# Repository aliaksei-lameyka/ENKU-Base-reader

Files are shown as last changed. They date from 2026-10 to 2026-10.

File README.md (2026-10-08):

# ENKU Base Reader

ENKU Base Reader is an independently developed, compact **3.97-inch e-paper reader** built around a custom ESP32-S3 mainboard. The goal is an inspectable, repairable, local-first reading device with physical controls, removable storage, and no required cloud account or subscription for reading locally stored books.

> **Status: Base R0.1 — engineering / first-spin development.** The board has **not** passed its fabrication release gate. Files in this repository are not a PCBWay-ready production package.

## Base R0.1 at a glance

| Area | Current engineering baseline |
| --- | --- |
| Display | 3.97-inch, 800 × 480 e-paper panel interface; 24-pin FPC |
| MCU | ESP32-S3-WROOM-1-N16R8 |
| PCB | 4 layers; 54 × 94 mm current outline; portrait-first |
| Storage and connectivity | microSD, USB-C |
| Navigation | Four side-edge buttons, two per side, for configurable left/right-handed controls |
| Motion sensing | BMI270 IMU |
| Power | Li-ion charging, USB/dock power-path handling, 3.3 V regulation, hard power switch |
| Dock | Rear dock connection and detection interface |

A Hall sensor is **still present in the current R0.1 design**, but its necessity is under review: Base is not being designed around a magnetic cover. Its presence in the design files should not be interpreted as a committed product feature.

**Outside the Base R0.1 scope:** frontlight and wireless charging. A separate, more fully featured variant may address these later; no Pro hardware is released here.

## Current work and limitations

The KiCad schematics, PCB, project-local libraries, and structural validation scripts are available. Routing closure, display-flex geometry, component orientation, mechanical interfaces, and manufacturing-file review are still release blockers.

The engineering goals are low-power operation, repairability, and reproducibility; they are **design goals, not yet verified production specifications**. Firmware and enclosure sources are not yet published in this repository.

## Repository guide

- [KiCad source and validation scripts](hardware/mainboard/kicad/) — editable mainboard design and engineering checks
- [Mainboard notes](hardware/mainboard/README.md) — current hardware release scope
- [Hardware overview](docs/hardware.md) — interfaces, controls, and mechanical envelope
- [Validation and fabrication gate](docs/validation.md) — checks required before ordering boards
- [Manufacturing notes](docs/manufacturing.md) — release package expectations
- [CI workflows](.github/workflows/) — structural and native KiCad checks

Manufacturing outputs (Gerber, drill, BOM, CPL, and assembly notes) will be published under `hardware/mainboard/production/<revision>/` **only after** a revision is approved for fabrication.

## Running the lightweight checks

From the repository root, with Python 3:

```sh
python3 hardware/mainboard/kicad/check_schematics.py
python3 hardware/mainboard/kicad/check_pcb_placement.py
python3 hardware/mainboard/kicad/check_footprint_consistency.py
python3 hardware/mainboard/kicad/check_pcb_population.py
```

These scripts catch structural and placement regressions. **They are not substitutes for native KiCad ERC/DRC** or an electrical/mechanical review. The repository includes a native KiCad workflow for pull requests and manual execution; a passing workflow alone does not authorize fabrication. See the [release checklist](docs/validation.md).

## Revisions

| Revision | Purpose | Status |
| --- | --- | --- |
| Base R0.1 | First engineering board / EVT | In development |
| Base R0.2 | Bring-up and first-spin corrections | Planned |
| Base R1.0 | Production candidate | Planned |

## Licensing

ENKU Base Reader uses **different licenses for different types of work**:

- **Original hardware design** — [CERN-OHL-W-2.0](LICENSE), including the KiCad PCB/schematic design and ENKU-authored hardware files.
- **Software and automation scripts** — [MIT](LICENSES/MIT.txt), including the Python validation tools and any future firmware expressly released in this repository.
- **Original project documentation** — [CC BY 4.0](LICENSES/CC-BY-4.0.txt), including README files and `docs/`.

Read the [license scope and third-party exceptions](LICENSE.md) before redistributing files or manufacturing modified boards. Third-party materials keep their own terms. The ENKU name and logos are not granted as trademarks by these licenses.

## Related project

[ENKU Originals](https://github.com/aliaksei-lameyka/ENKU-Originals) is a separate, early-stage experiment in AI-assisted, human-edited short fiction and reader-first EPUB delivery. It is currently private. **Its stories and editorial content are not licensed by this repository.**

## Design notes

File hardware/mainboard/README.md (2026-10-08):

# ENKU Base mainboard

Editable **Base R0.1** schematic, PCB and local KiCad libraries are stored in [`kicad/`](kicad/).

This is an **engineering first-spin**, not a fabrication-ready or production release. Before any manufacturing order, complete the [fabrication release checklist](../../docs/validation.md), including native KiCad ERC/DRC, connector orientation, component selections, display FPC fit and manufacturing-output review.

The Base does **not** include frontlight or wireless-charging circuitry. Those are outside this board's scope.

The original ENKU hardware design is licensed under **CERN-OHL-W-2.0**; see the repository [licensing guide](../../LICENSE.md). Automation scripts in `kicad/` are under MIT.

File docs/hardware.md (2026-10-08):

# Hardware overview

## Base R0.1

Base R0.1 is a four-layer mainboard for the compact ENKU reader.

### Compute and storage

- ESP32-S3-WROOM-1-N16R8
- microSD
- USB-C USB 2.0 connection

### Display

The board carries a dedicated 24-pin e-paper interface and local high-voltage generation for the 3.97-inch panel class used by the first reader prototype. The display FPC orientation and bend path still require mechanical verification.

### Power

The power architecture includes USB/dock source handling, Li-ion charging, a hard power control path and a 3.3 V system rail.

### Input and sensing

- Two reading buttons on each side edge
- BMI270 IMU
- Hall sensor **present in the current design, under review for Base**
- Service/debug interface
- Dock detect

The four reading buttons are intentionally symmetric so firmware can support left-handed and right-handed layouts. A magnetic-cover feature is **not** in the Base product scope; the Hall sensor's inclusion is therefore not yet a final feature decision.

### Base scope

Frontlight and wireless charging are not part of Base R0.1. Keeping those features out of the first-spin board reduces routing and validation complexity and lets the Base hardware reach bring-up sooner.

## Mechanical envelope

The current PCB outline is 54 × 94 mm in portrait orientation.

Mechanical release still requires final validation of the display flex path, USB-C opening, microSD insertion envelope, battery lead exit, dock contact face, hard-power actuator and side-button actuators against the enclosure master.

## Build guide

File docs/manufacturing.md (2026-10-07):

# Manufacturing notes

Base R0.1 is an engineering first-spin board. Manufacturing outputs are not considered authoritative until the fabrication release gate is closed.

## Board

- 4 layers
- 54 × 94 mm outline
- portrait primary orientation

The KiCad source under `hardware/mainboard/kicad/` is the editable source of truth.

## Assembly package

A release package will contain:

- Gerber files
- NC drill files
- BOM
- pick-and-place / CPL
- assembly notes
- board preview
- revision identifier

Generated outputs belong under `hardware/mainboard/production/<revision>/` and should not be edited by hand.

## First-spin priorities

For the first fabrication run, debug access and repairability take priority over cosmetic density. Important power rails and e-paper high-voltage rails retain measurement access where practical.

Component reference markings and polarity/orientation cues should remain readable after assembly wherever board space allows.

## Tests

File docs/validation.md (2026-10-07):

# Validation

The repository uses two levels of checks.

## Lightweight checks

Structural checks run on hardware changes and catch issues that do not require KiCad itself:

- schematic hierarchy integrity
- required Base references and nets
- PCB population parity
- project-local footprint consistency
- placement and orientation invariants
- selected routing regression checks

These checks are intentionally fast.

## Native KiCad checks

Native KiCad ERC and DRC are the authority for electrical and PCB-rule validation.

They are used at meaningful engineering gates rather than as an interactive router. A passing structural check does not replace native ERC/DRC.

## Fabrication release gate

Before Base R0.1 can be released for fabrication, the board must have:

1. final Base routing closed;
2. no unexplained ERC errors;
3. no fabrication-blocking DRC violations;
4. final battery connector selected and polarity verified;
5. final hard-power switch selected and actuator geometry verified;
6. final side-button switch selected and enclosure interaction verified;
7. e-paper FPC pin 1, contact side and bend path verified against the selected panel;
8. USB-C and microSD mechanical access checked against enclosure geometry;
9. dock pogo face and pin order checked;
10. Gerber, drill, BOM and pick-and-place outputs visually reviewed.

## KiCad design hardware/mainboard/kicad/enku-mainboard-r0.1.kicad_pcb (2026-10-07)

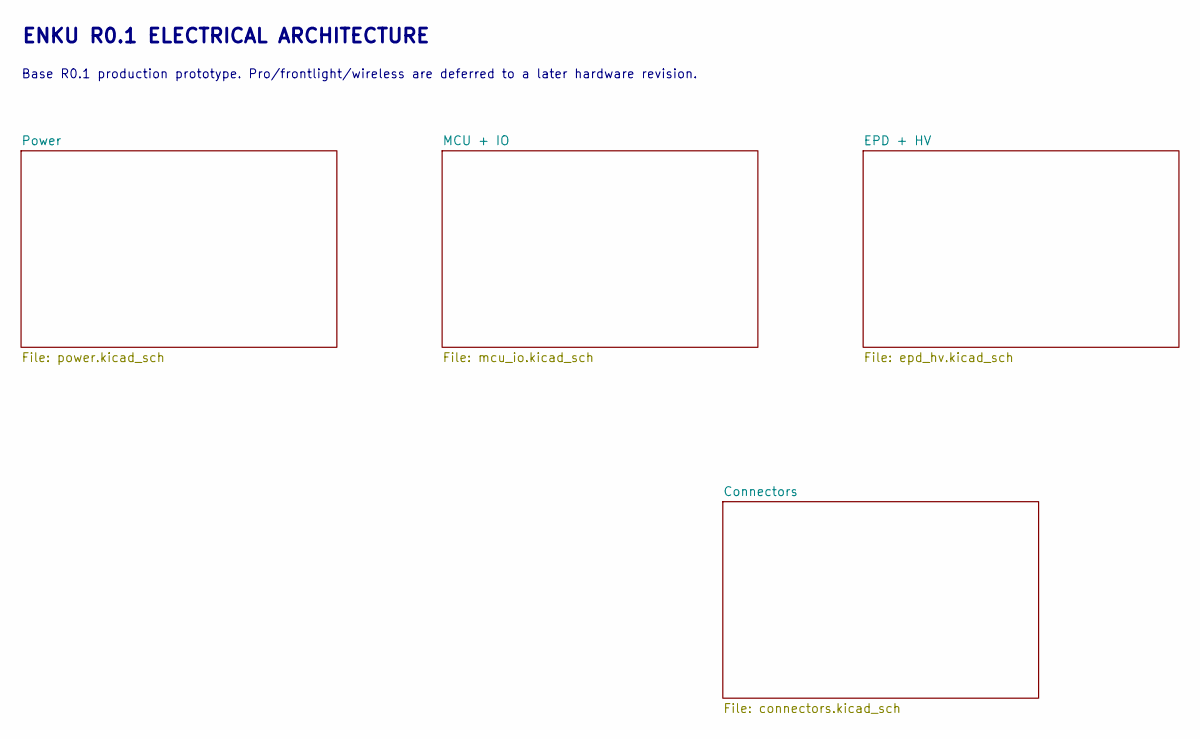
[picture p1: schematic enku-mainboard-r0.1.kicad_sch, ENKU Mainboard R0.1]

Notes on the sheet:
ENKU R0.1 ELECTRICAL ARCHITECTURE
Base R0.1 production prototype. Pro/frontlight/wireless are deferred to a later hardware revision.

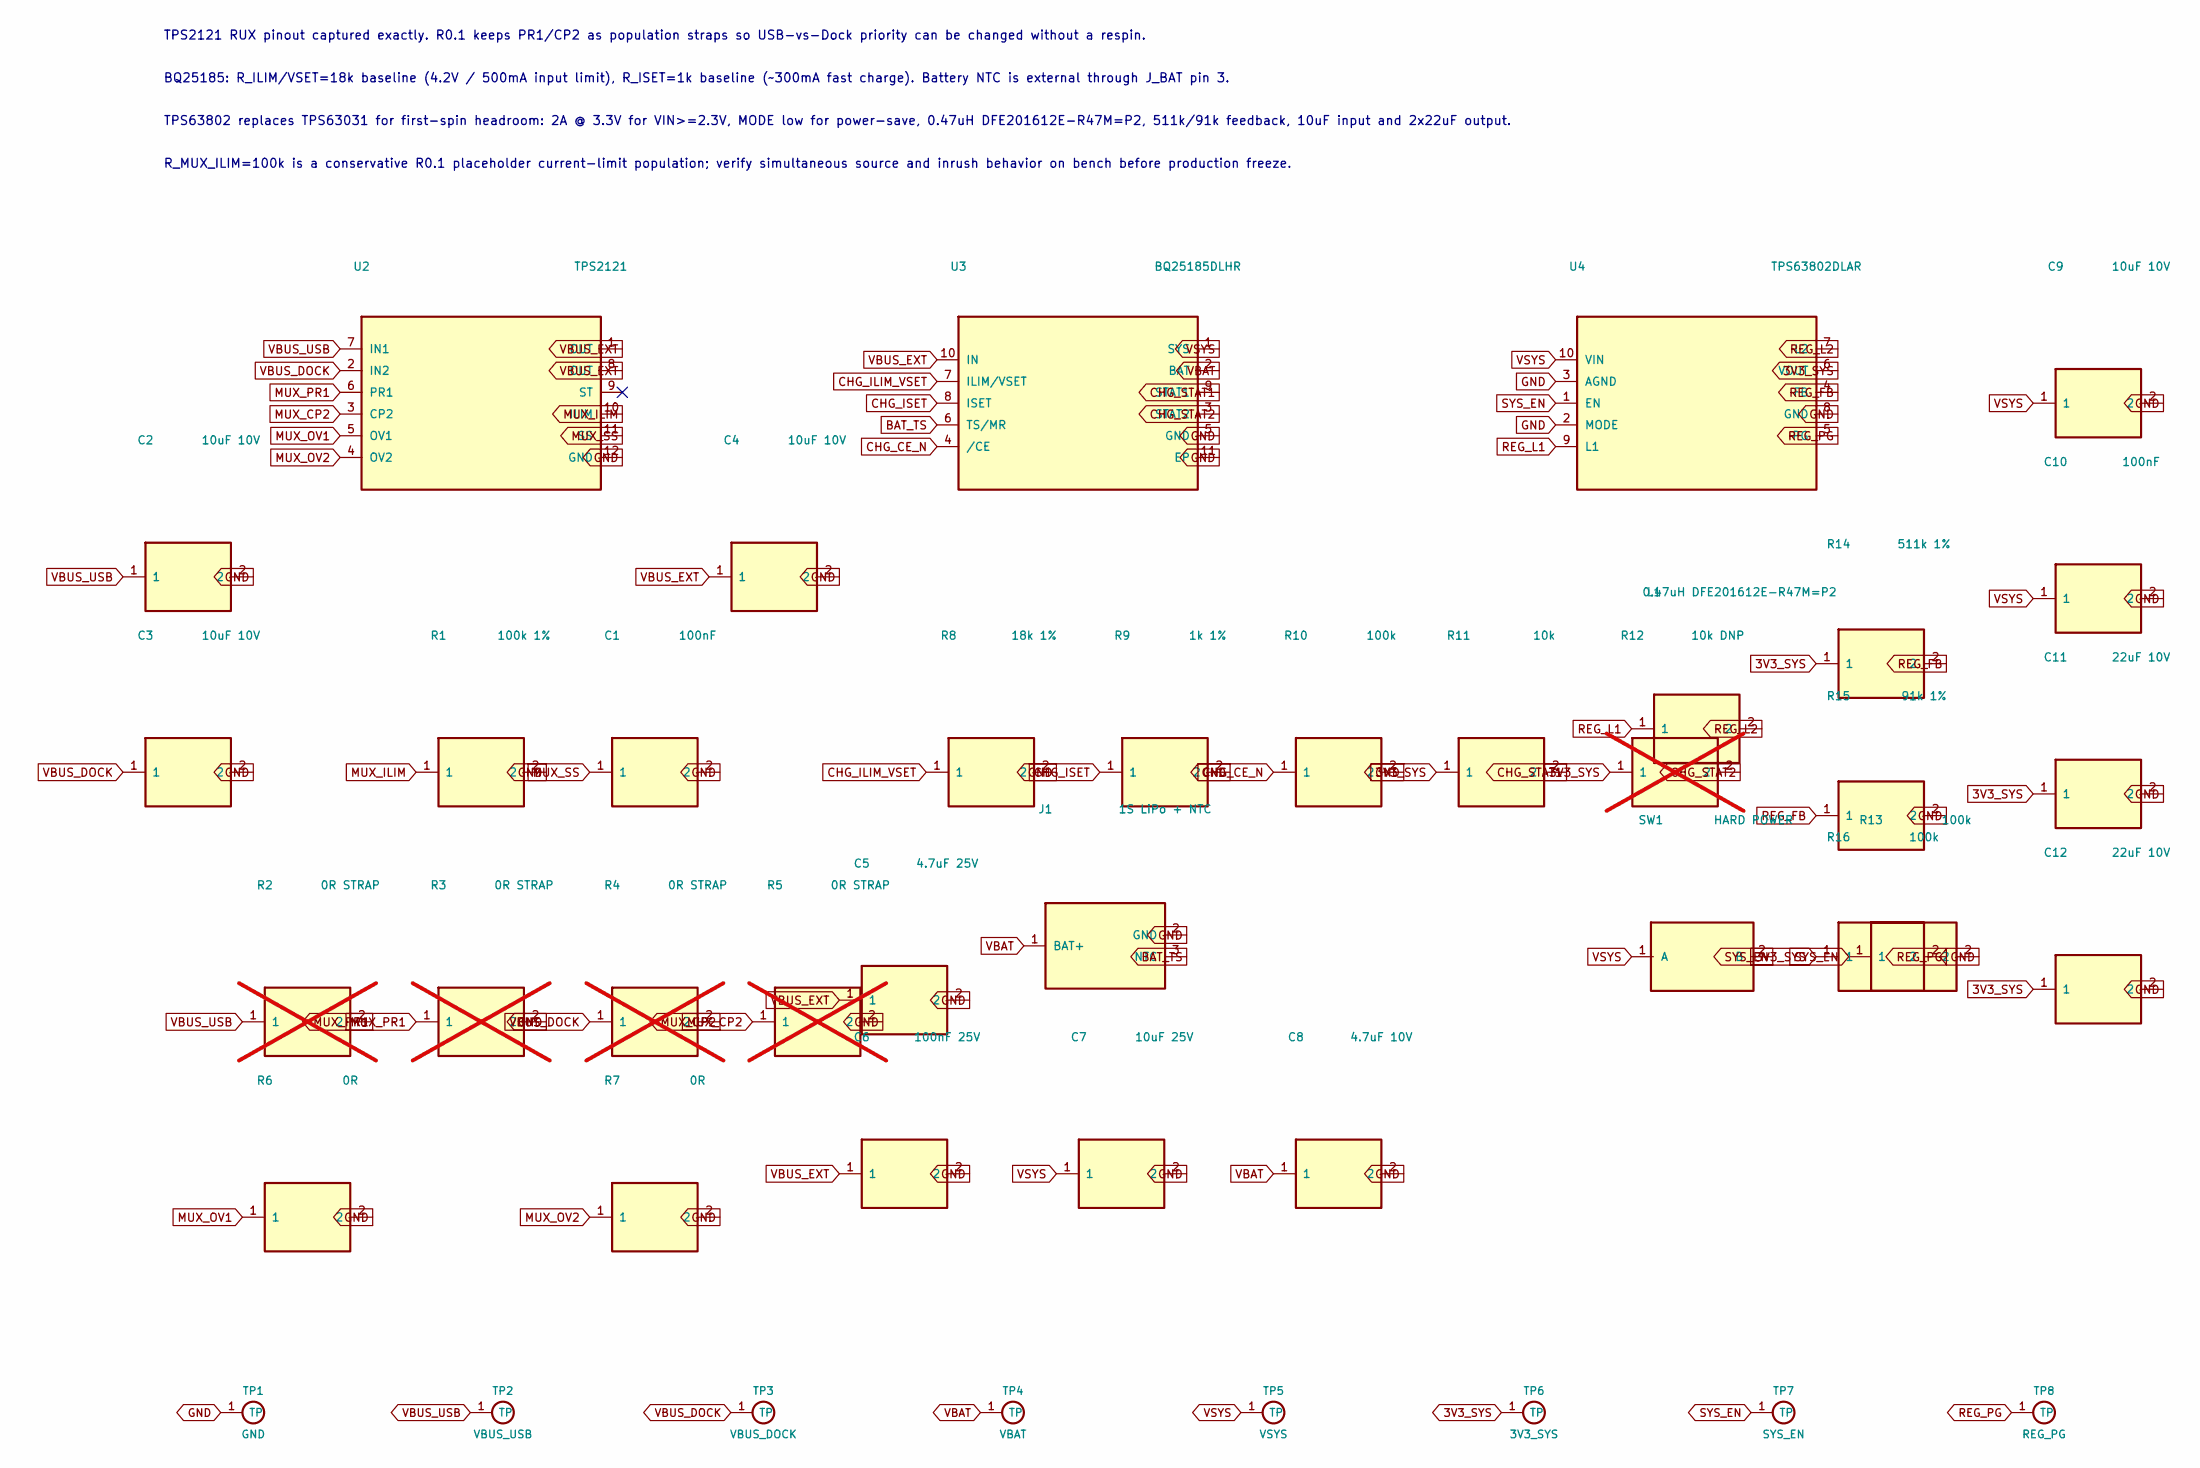
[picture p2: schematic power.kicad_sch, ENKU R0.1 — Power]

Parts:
C1, C10: 100nF; C_0603_1608Metric
C2, C3, C4, C9: 10uF 10V; C_0805_2012Metric
C5: 4.7uF 25V; C_0805_2012Metric
C6: 100nF 25V; C_0603_1608Metric
C7: 10uF 25V; C_0805_2012Metric
C8: 4.7uF 10V; C_0805_2012Metric
C11, C12: 22uF 10V; C_0805_2012Metric
J1: 1S LiPo + NTC; JST_PH_3_PLACEMENT
L1: 0.47uH DFE201612E-R47M=P2; Murata_DFE201612E
R1: 100k 1%; R_0603_1608Metric
R2, R3, R4, R5: 0R STRAP; R_0603_1608Metric; not fitted
R6, R7: 0R; R_0603_1608Metric
R8: 18k 1%; R_0603_1608Metric
R9: 1k 1%; R_0603_1608Metric
R10, R13, R16: 100k; R_0603_1608Metric
R11: 10k; R_0603_1608Metric
R12: 10k DNP; R_0603_1608Metric; not fitted
R14: 511k 1%; R_0603_1608Metric
R15: 91k 1%; R_0603_1608Metric
SW1: HARD POWER; HARD_POWER_SWITCH_PLACEMENT
TP1: GND; TestPoint_Pad_D1.5mm
TP2: VBUS_USB; TestPoint_Pad_D1.5mm
TP3: VBUS_DOCK; TestPoint_Pad_D1.5mm
TP4: VBAT; TestPoint_Pad_D1.5mm
TP5: VSYS; TestPoint_Pad_D1.5mm
TP6: 3V3_SYS; TestPoint_Pad_D1.5mm
TP7: SYS_EN; TestPoint_Pad_D1.5mm
TP8: REG_PG; TestPoint_Pad_D1.5mm
U2: TPS2121; TPS2121_RUX0012A
U3: BQ25185DLHR; BQ25185_DLH0010A
U4: TPS63802DLAR; TPS63802_DLA0010A

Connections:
3V3_SYS: C11.1, C12.1, R11.1, R12.1, R14.1, R16.1, TP6.1, U4.6 (VOUT); also elsewhere on the board
BAT_TS: J1.3 (NTC), U3.6 (TS/MR)
CHG_CE_N: R10.1, U3.4 (/CE)
CHG_ILIM_VSET: R8.1, U3.7 (ILIM/VSET)
CHG_ISET: R9.1, U3.8 (ISET)
CHG_STAT1: R11.2, U3.9 (STAT1); also elsewhere on the board
CHG_STAT2: R12.2, U3.3 (STAT2)
GND: C1.2, C2.2, C3.2, C4.2, C5.2, C6.2, C7.2, C8.2, C9.2, C10.2, C11.2, C12.2, J1.2 (GND), R1.2, R3.2, R5.2, R6.2, R7.2, R8.2, R9.2, R10.2, R13.2, R15.2, TP1.1, U2.12 (GND), U3.5 (GND), U3.11 (EP), U4.2 (MODE), U4.3 (AGND), U4.8 (GND); also elsewhere on the board
MUX_CP2: R4.2, R5.1, U2.3 (CP2)
MUX_ILIM: R1.1, U2.10 (ILIM)
MUX_OV1: R6.1, U2.5 (OV1)
MUX_OV2: R7.1, U2.4 (OV2)
MUX_PR1: R2.2, R3.1, U2.6 (PR1)
MUX_SS: C1.1, U2.11 (SS)
REG_FB: R14.2, R15.1, U4.4 (FB)
REG_L1: L1.1, U4.9 (L1)
REG_L2: L1.2, U4.7 (L2)
REG_PG: R16.2, TP8.1, U4.5 (PG)
SYS_EN: R13.1, SW1.2 (B), TP7.1, U4.1 (EN)
VBAT: C8.1, J1.1 (BAT+), TP4.1, U3.2 (BAT); also elsewhere on the board
VBUS_DOCK: C3.1, R4.1, TP3.1, U2.2 (IN2); also elsewhere on the board
VBUS_EXT: C4.1, C5.1, C6.1, U2.1 (OUT), U2.8 (OUT), U3.10 (IN)
VBUS_USB: C2.1, R2.1, TP2.1, U2.7 (IN1); also elsewhere on the board
VSYS: C7.1, C9.1, C10.1, SW1.1 (A), TP5.1, U3.1 (SYS), U4.10 (VIN)

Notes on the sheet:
TPS2121 RUX pinout captured exactly. R0.1 keeps PR1/CP2 as population straps so USB-vs-Dock priority can be changed without a respin.
BQ25185: R_ILIM/VSET=18k baseline (4.2V / 500mA input limit), R_ISET=1k baseline (~300mA fast charge). Battery NTC is external through J_BAT pin 3.
TPS63802 replaces TPS63031 for first-spin headroom: 2A @ 3.3V for VIN>=2.3V, MODE low for power-save, 0.47uH DFE201612E-R47M=P2, 511k/91k feedback, 10uF input and 2x22uF output.
R_MUX_ILIM=100k is a conservative R0.1 placeholder current-limit population; verify simultaneous source and inrush behavior on bench before production freeze.

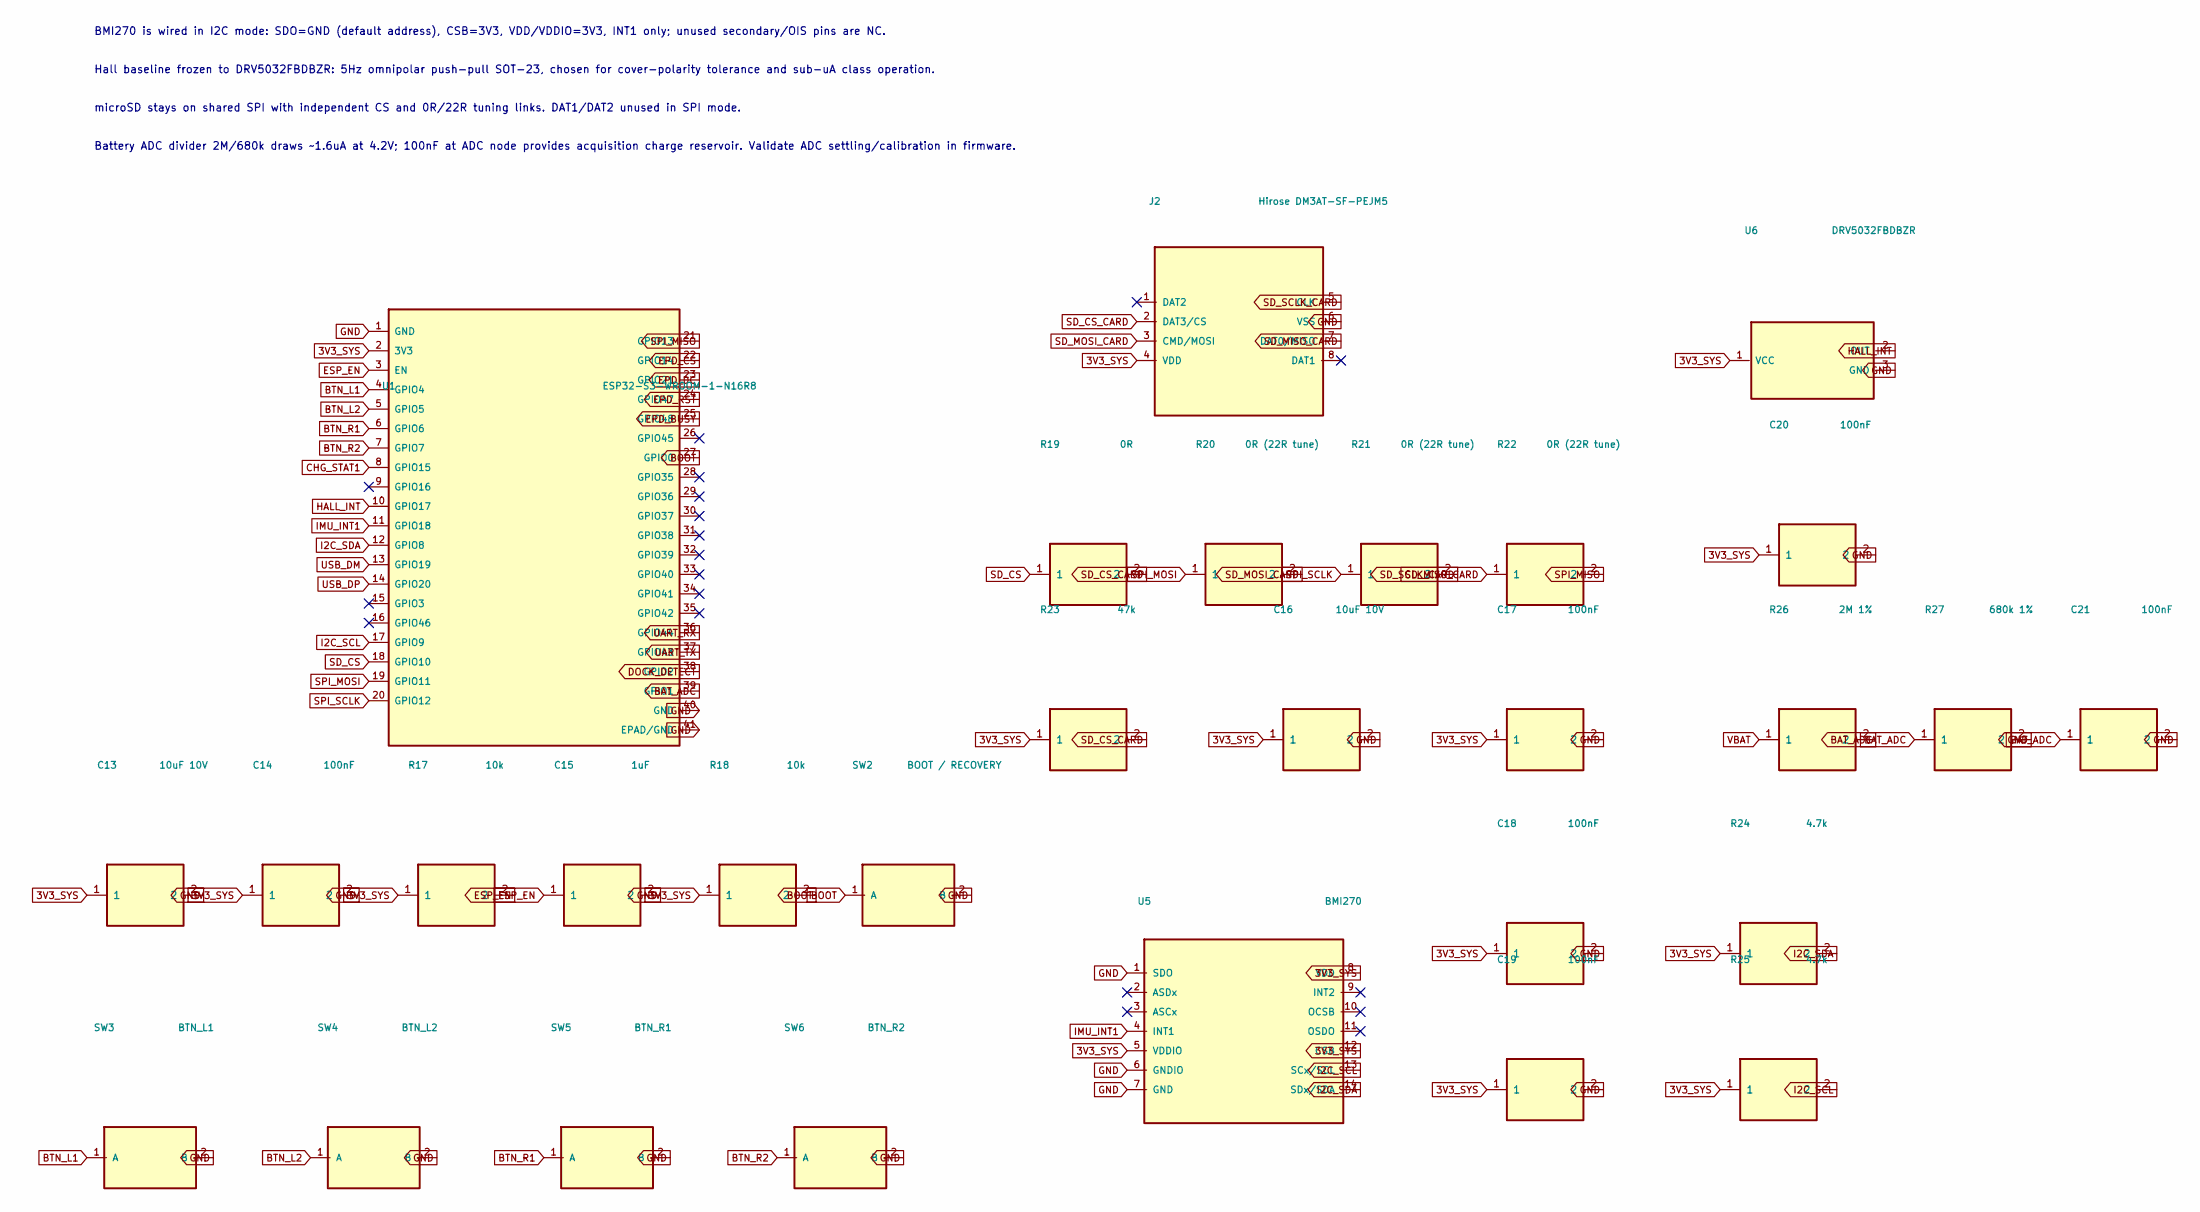
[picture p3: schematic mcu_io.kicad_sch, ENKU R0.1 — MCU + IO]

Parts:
C13, C16: 10uF 10V; C_0805_2012Metric
C14, C17, C18, C19, C20, C21: 100nF; C_0603_1608Metric
C15: 1uF; C_0603_1608Metric
J2: Hirose DM3AT-SF-PEJM5; MICROSD_DM3AT_ENKU
R17, R18: 10k; R_0603_1608Metric
R19: 0R; R_0603_1608Metric
R20, R21, R22: 0R (22R tune); R_0603_1608Metric
R23: 47k; R_0603_1608Metric
R24, R25: 4.7k; R_0603_1608Metric
R26: 2M 1%; R_0603_1608Metric
R27: 680k 1%; R_0603_1608Metric
SW2: BOOT / RECOVERY; SW_SPST_TL3342
SW3: BTN_L1; READING_BUTTON_PLACEMENT
SW4: BTN_L2; READING_BUTTON_PLACEMENT
SW5: BTN_R1; READING_BUTTON_PLACEMENT
SW6: BTN_R2; READING_BUTTON_PLACEMENT
U1: ESP32-S3-WROOM-1-N16R8; ESP32-S3-WROOM-1
U5: BMI270; BMI270_Bosch_LGA14
U6: DRV5032FBDBZR; SOT-23

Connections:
3V3_SYS: C13.1, C14.1, C16.1, C17.1, C18.1, C19.1, C20.1, J2.4 (VDD), R17.1, R18.1, R23.1, R24.1, R25.1, U1.2 (3V3), U5.5 (VDDIO), U5.8 (VDD), U5.12 (CSB), U6.1 (VCC); also elsewhere on the board
BAT_ADC: C21.1, R26.2, R27.1, U1.39 (GPIO1)
BOOT: R18.2, SW2.1 (A), U1.27 (GPIO0); also elsewhere on the board
BTN_L1: SW3.1 (A), U1.4 (GPIO4)
BTN_L2: SW4.1 (A), U1.5 (GPIO5)
BTN_R1: SW5.1 (A), U1.6 (GPIO6)
BTN_R2: SW6.1 (A), U1.7 (GPIO7)
CHG_STAT1: U1.8 (GPIO15); also elsewhere on the board
DOCK_DETECT: U1.38 (GPIO2); also elsewhere on the board
EPD_BUSY: U1.25 (GPIO48); also elsewhere on the board
EPD_CS: U1.22 (GPIO14); also elsewhere on the board
EPD_DC: U1.23 (GPIO21); also elsewhere on the board
EPD_RST: U1.24 (GPIO47); also elsewhere on the board
ESP_EN: C15.1, R17.2, U1.3 (EN); also elsewhere on the board
GND: C13.2, C14.2, C15.2, C16.2, C17.2, C18.2, C19.2, C20.2, C21.2, J2.6 (VSS), R27.2, SW2.2 (B), SW3.2 (B), SW4.2 (B), SW5.2 (B), SW6.2 (B), U1.1 (GND), U1.40 (GND), U1.41 (EPAD/GND), U5.1 (SDO), U5.6 (GNDIO), U5.7 (GND), U6.3 (GND); also elsewhere on the board
HALL_INT: U1.10 (GPIO17), U6.2 (OUT)
I2C_SCL: R25.2, U1.17 (GPIO9), U5.13 (SCx/SCL)
I2C_SDA: R24.2, U1.12 (GPIO8), U5.14 (SDx/SDA)
IMU_INT1: U1.11 (GPIO18), U5.4 (INT1)
SD_CS: R19.1, U1.18 (GPIO10)
SD_CS_CARD: J2.2 (DAT3/CS), R19.2, R23.2
SD_MISO_CARD: J2.7 (DAT0/MISO), R22.1
SD_MOSI_CARD: J2.3 (CMD/MOSI), R20.2
SD_SCLK_CARD: J2.5 (CLK), R21.2
SPI_MISO: R22.2, U1.21 (GPIO13)
SPI_MOSI: R20.1, U1.19 (GPIO11); also elsewhere on the board
SPI_SCLK: R21.1, U1.20 (GPIO12); also elsewhere on the board
UART_RX: U1.36 (GPIO44); also elsewhere on the board
UART_TX: U1.37 (GPIO43); also elsewhere on the board
USB_DM: U1.13 (GPIO19); also elsewhere on the board
USB_DP: U1.14 (GPIO20); also elsewhere on the board
VBAT: R26.1; also elsewhere on the board

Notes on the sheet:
BMI270 is wired in I2C mode: SDO=GND (default address), CSB=3V3, VDD/VDDIO=3V3, INT1 only; unused secondary/OIS pins are NC.
Hall baseline frozen to DRV5032FBDBZR: 5Hz omnipolar push-pull SOT-23, chosen for cover-polarity tolerance and sub-uA class operation.
microSD stays on shared SPI with independent CS and 0R/22R tuning links. DAT1/DAT2 unused in SPI mode.
Battery ADC divider 2M/680k draws ~1.6uA at 4.2V; 100nF at ADC node provides acquisition charge reservoir. Validate ADC settling/calibration in firmware.

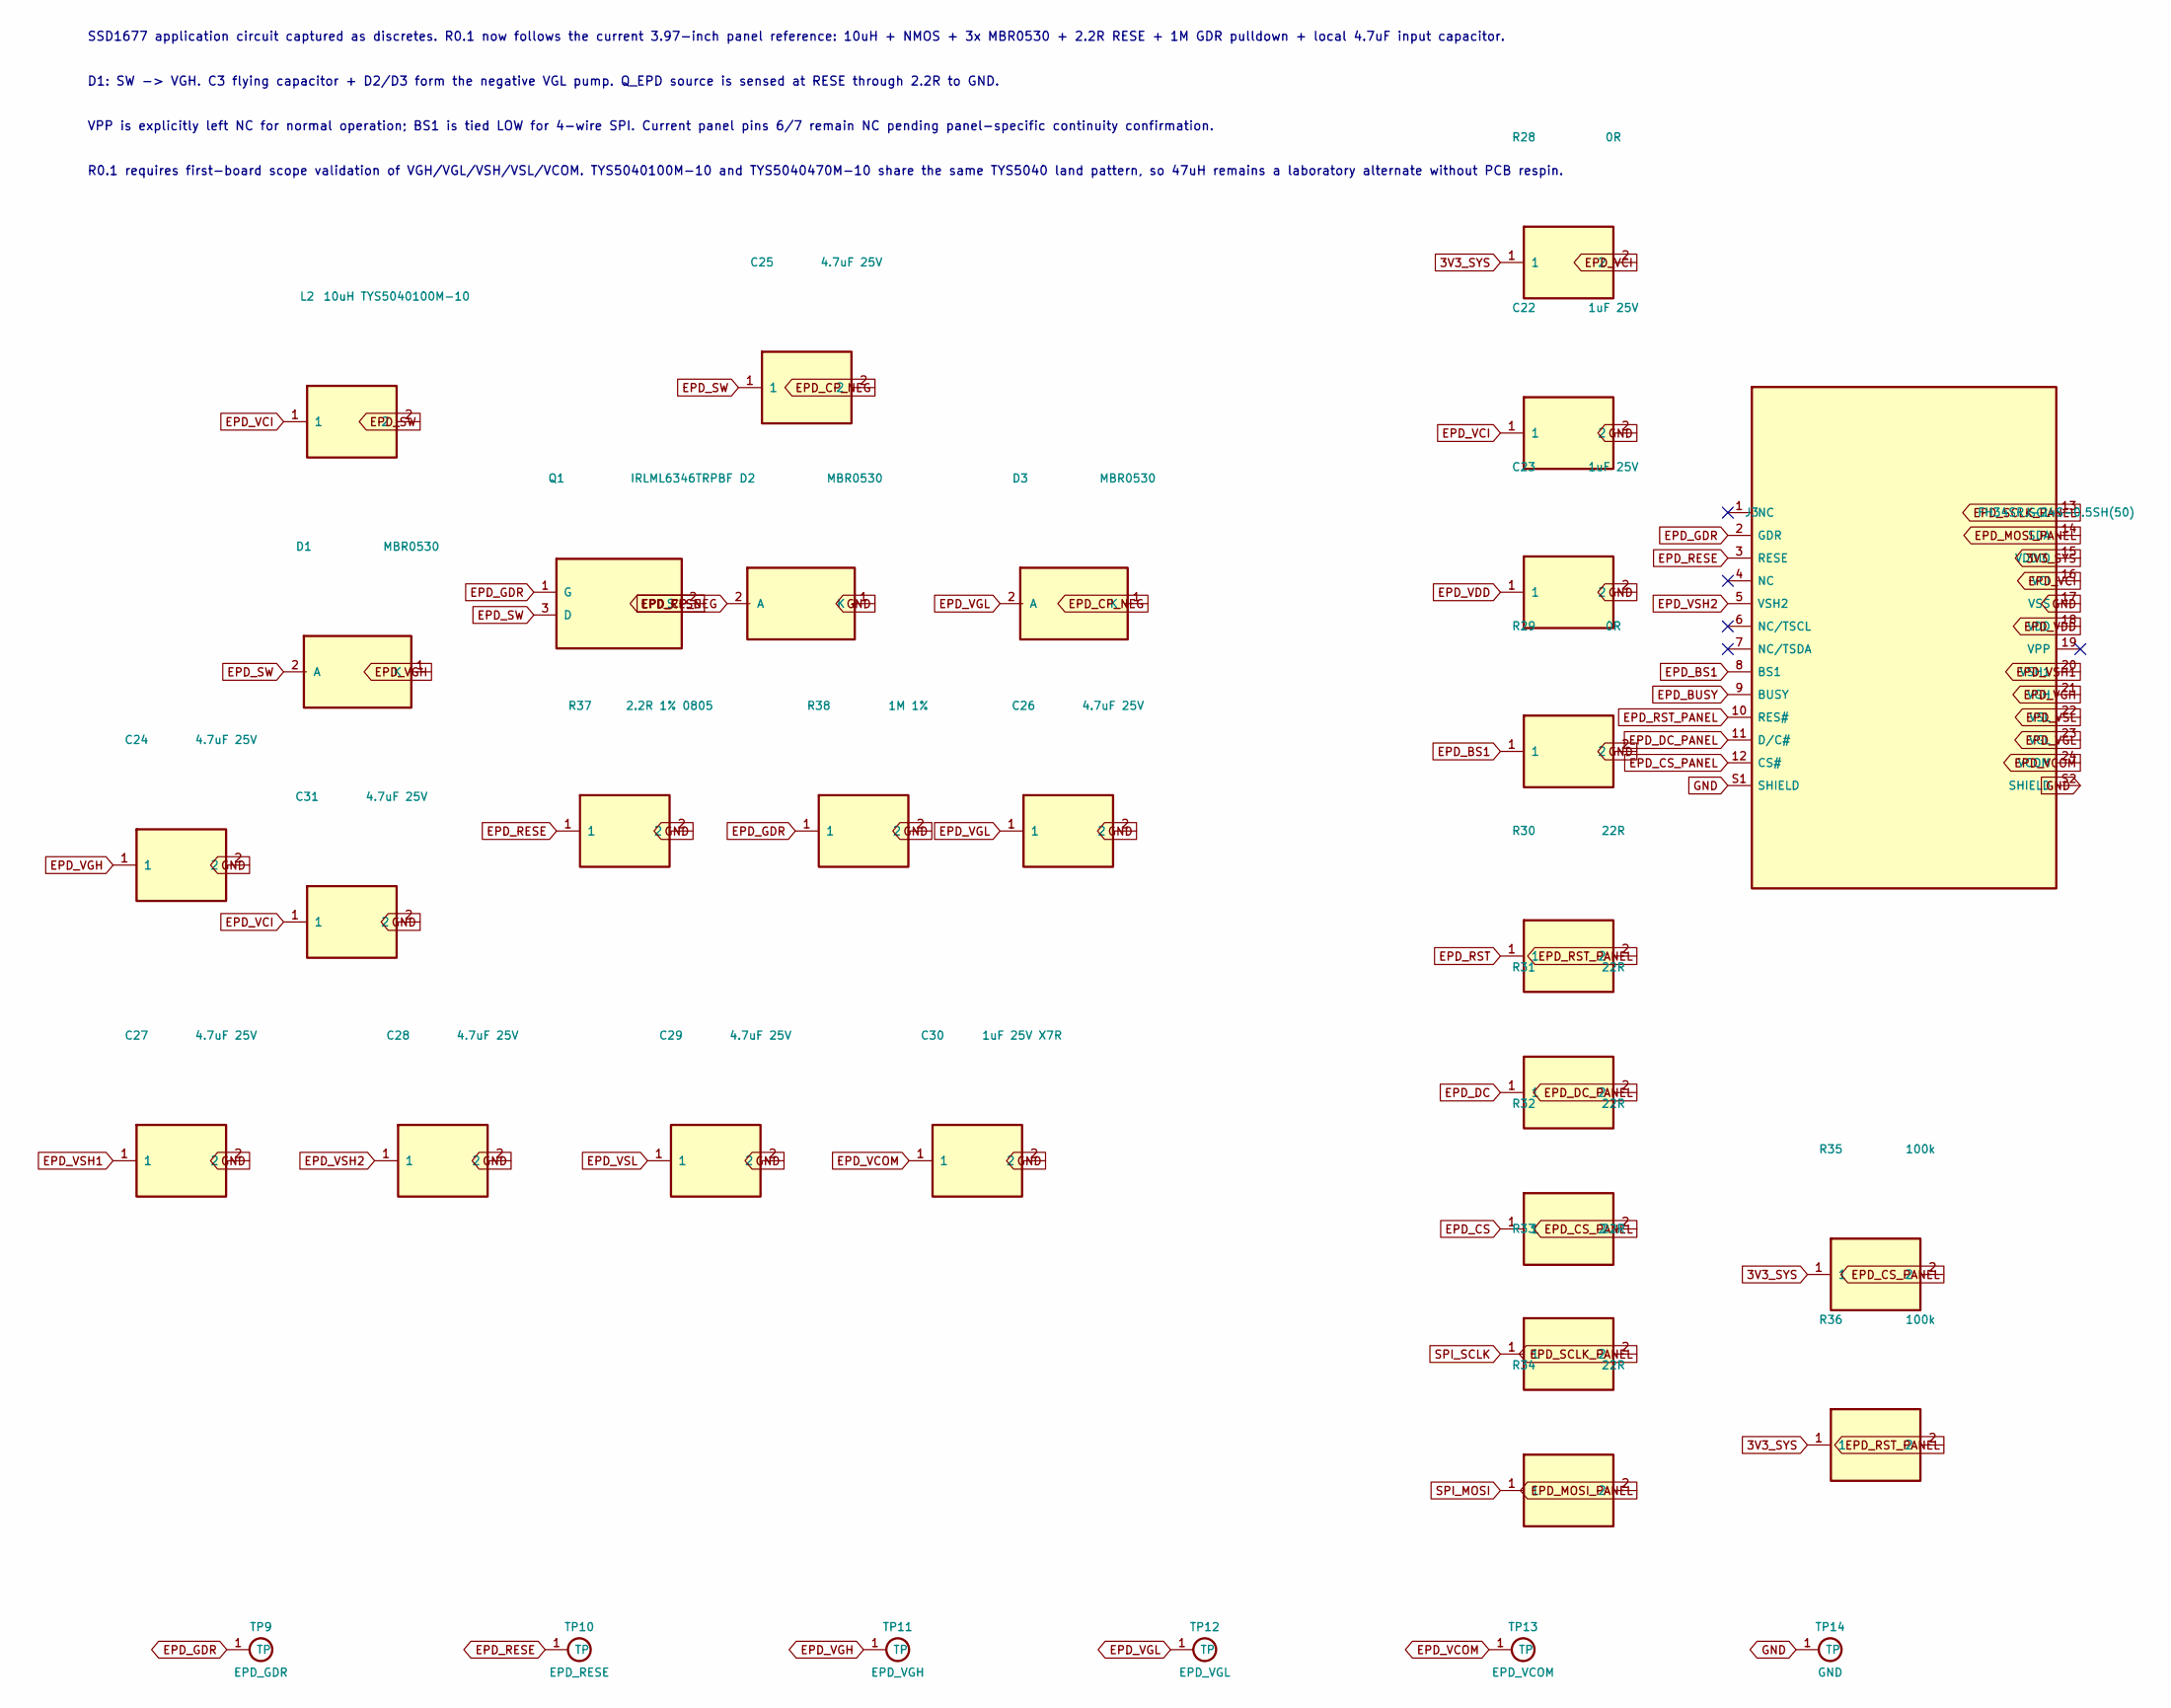
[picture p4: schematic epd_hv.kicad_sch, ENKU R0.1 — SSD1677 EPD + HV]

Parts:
C22, C23: 1uF 25V; C_0603_1608Metric
C24, C25, C26, C27, C28, C29, C31: 4.7uF 25V; C_0805_2012Metric
C30: 1uF 25V X7R; C_0805_2012Metric
D1, D2, D3: MBR0530; D_SOD-123
J3: FH34SRJ-24S-0.5SH(50); FH34SRJ-24S-0.5SH
L2: 10uH TYS5040100M-10; TYS5040_5x5
Q1: IRLML6346TRPBF; SOT-23
R28, R29: 0R; R_0603_1608Metric
R30, R31, R32, R33, R34: 22R; R_0603_1608Metric
R35, R36: 100k; R_0603_1608Metric
R37: 2.2R 1% 0805; R_0805_2012Metric
R38: 1M 1%; R_0603_1608Metric
TP9: EPD_GDR; TestPoint_Pad_D1.5mm
TP10: EPD_RESE; TestPoint_Pad_D1.5mm
TP11: EPD_VGH; TestPoint_Pad_D1.5mm
TP12: EPD_VGL; TestPoint_Pad_D1.5mm
TP13: EPD_VCOM; TestPoint_Pad_D1.5mm
TP14: GND; TestPoint_Pad_D1.5mm

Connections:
3V3_SYS: J3.15 (VDDIO), R28.1, R35.1, R36.1; also elsewhere on the board
EPD_BS1: J3.8 (BS1), R29.1
EPD_BUSY: J3.9 (BUSY); also elsewhere on the board
EPD_CP_NEG: C25.2, D2.2 (A), D3.1 (K)
EPD_CS: R32.1; also elsewhere on the board
EPD_CS_PANEL: J3.12 (CS#), R32.2, R35.2
EPD_DC: R31.1; also elsewhere on the board
EPD_DC_PANEL: J3.11 (D/C#), R31.2
EPD_GDR: J3.2 (GDR), Q1.1 (G), R38.1, TP9.1
EPD_MOSI_PANEL: J3.14 (SDA), R34.2
EPD_RESE: J3.3 (RESE), Q1.2 (S), R37.1, TP10.1
EPD_RST: R30.1; also elsewhere on the board
EPD_RST_PANEL: J3.10 (RES#), R30.2, R36.2
EPD_SCLK_PANEL: J3.13 (SCL), R33.2
EPD_SW: C25.1, D1.2 (A), L2.2, Q1.3 (D)
EPD_VCI: C22.1, C31.1, J3.16 (VCI), L2.1, R28.2
EPD_VCOM: C30.1, J3.24 (VCOM), TP13.1
EPD_VDD: C23.1, J3.18 (VDD)
EPD_VGH: C24.1, D1.1 (K), J3.21 (VGH), TP11.1
EPD_VGL: C26.1, D3.2 (A), J3.23 (VGL), TP12.1
EPD_VSH1: C27.1, J3.20 (VSH1)
EPD_VSH2: C28.1, J3.5 (VSH2)
EPD_VSL: C29.1, J3.22 (VSL)
GND: C22.2, C23.2, C24.2, C26.2, C27.2, C28.2, C29.2, C30.2, C31.2, D2.1 (K), J3.17 (VSS), J3.S1 (SHIELD), J3.S2 (SHIELD), R29.2, R37.2, R38.2, TP14.1; also elsewhere on the board
SPI_MOSI: R34.1; also elsewhere on the board
SPI_SCLK: R33.1; also elsewhere on the board

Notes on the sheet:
SSD1677 application circuit captured as discretes. R0.1 now follows the current 3.97-inch panel reference: 10uH + NMOS + 3x MBR0530 + 2.2R RESE + 1M GDR pulldown + local 4.7uF input capacitor.
D1: SW -> VGH. C3 flying capacitor + D2/D3 form the negative VGL pump. Q_EPD source is sensed at RESE through 2.2R to GND.
VPP is explicitly left NC for normal operation; BS1 is tied LOW for 4-wire SPI. Current panel pins 6/7 remain NC pending panel-specific continuity confirmation.
R0.1 requires first-board scope validation of VGH/VGL/VSH/VSL/VCOM. TYS5040100M-10 and TYS5040470M-10 share the same TYS5040 land pattern, so 47uH remains a laboratory alternate without PCB respin.

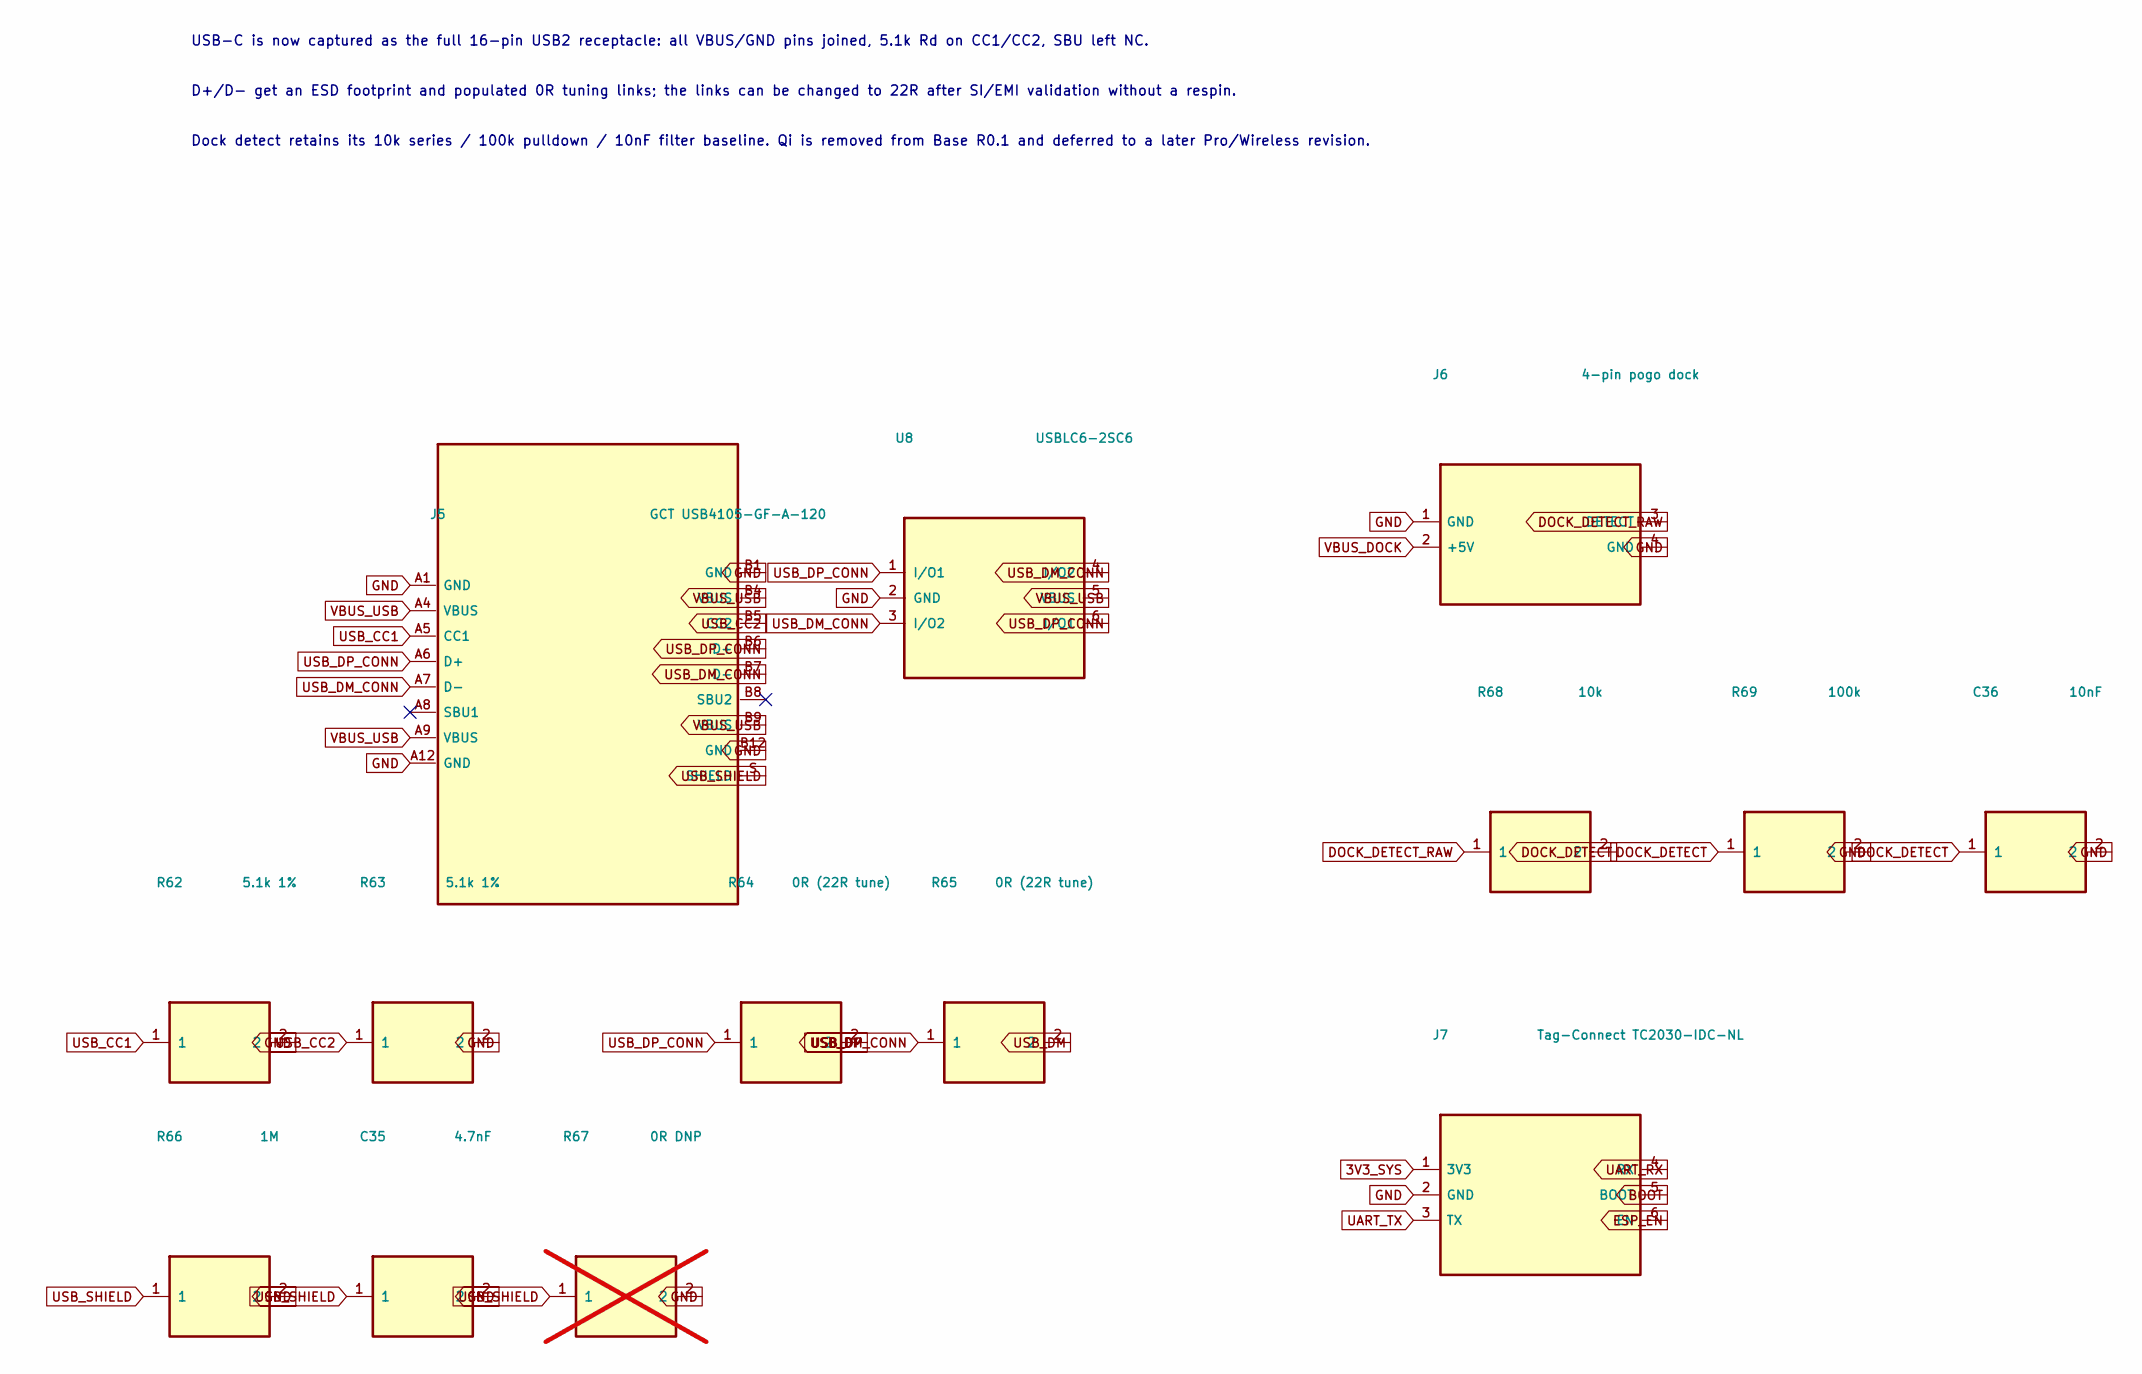
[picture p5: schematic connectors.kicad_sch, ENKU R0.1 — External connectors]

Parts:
C35: 4.7nF; C_0603_1608Metric
C36: 10nF; C_0603_1608Metric
J5: GCT USB4105-GF-A-120; USB_C_Receptacle_GCT_USB4105-xx-A_16P_TopMnt_Horizontal
J6: 4-pin pogo dock; DOCK_POGO_4
J7: Tag-Connect TC2030-IDC-NL; Tag-Connect_TC2030-IDC-NL_2x03_P1.27mm_Vertical
R62, R63: 5.1k 1%; R_0603_1608Metric
R64, R65: 0R (22R tune); R_0603_1608Metric
R66: 1M; R_0603_1608Metric
R67: 0R DNP; R_0603_1608Metric; not fitted
R68: 10k; R_0603_1608Metric
R69: 100k; R_0603_1608Metric
U8: USBLC6-2SC6; SOT-23-6

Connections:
3V3_SYS: J7.1 (3V3); also elsewhere on the board
BOOT: J7.5 (BOOT); also elsewhere on the board
DOCK_DETECT: C36.1, R68.2, R69.1; also elsewhere on the board
DOCK_DETECT_RAW: J6.3 (DETECT), R68.1
ESP_EN: J7.6 (EN); also elsewhere on the board
GND: C35.2, C36.2, J5.A1 (GND), J5.A12 (GND), J5.B1 (GND), J5.B12 (GND), J6.1 (GND), J6.4 (GND), J7.2 (GND), R62.2, R63.2, R66.2, R67.2, R69.2, U8.2 (GND); also elsewhere on the board
UART_RX: J7.4 (RX); also elsewhere on the board
UART_TX: J7.3 (TX); also elsewhere on the board
USB_CC1: J5.A5 (CC1), R62.1
USB_CC2: J5.B5 (CC2), R63.1
USB_DM: R65.2; also elsewhere on the board
USB_DM_CONN: J5.A7 (D-), J5.B7 (D-), R65.1, U8.3 (I/O2), U8.4 (I/O2)
USB_DP: R64.2; also elsewhere on the board
USB_DP_CONN: J5.A6 (D+), J5.B6 (D+), R64.1, U8.1 (I/O1), U8.6 (I/O1)
USB_SHIELD: C35.1, J5.S (SHIELD), R66.1, R67.1
VBUS_DOCK: J6.2 (+5V); also elsewhere on the board
VBUS_USB: J5.A4 (VBUS), J5.A9 (VBUS), J5.B4 (VBUS), J5.B9 (VBUS), U8.5 (VBUS); also elsewhere on the board

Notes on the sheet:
USB-C is now captured as the full 16-pin USB2 receptacle: all VBUS/GND pins joined, 5.1k Rd on CC1/CC2, SBU left NC.
D+/D- get an ESD footprint and populated 0R tuning links; the links can be changed to 22R after SI/EMI validation without a respin.
Dock detect retains its 10k series / 100k pulldown / 10nF filter baseline. Qi is removed from Base R0.1 and deferred to a later Pro/Wireless revision.

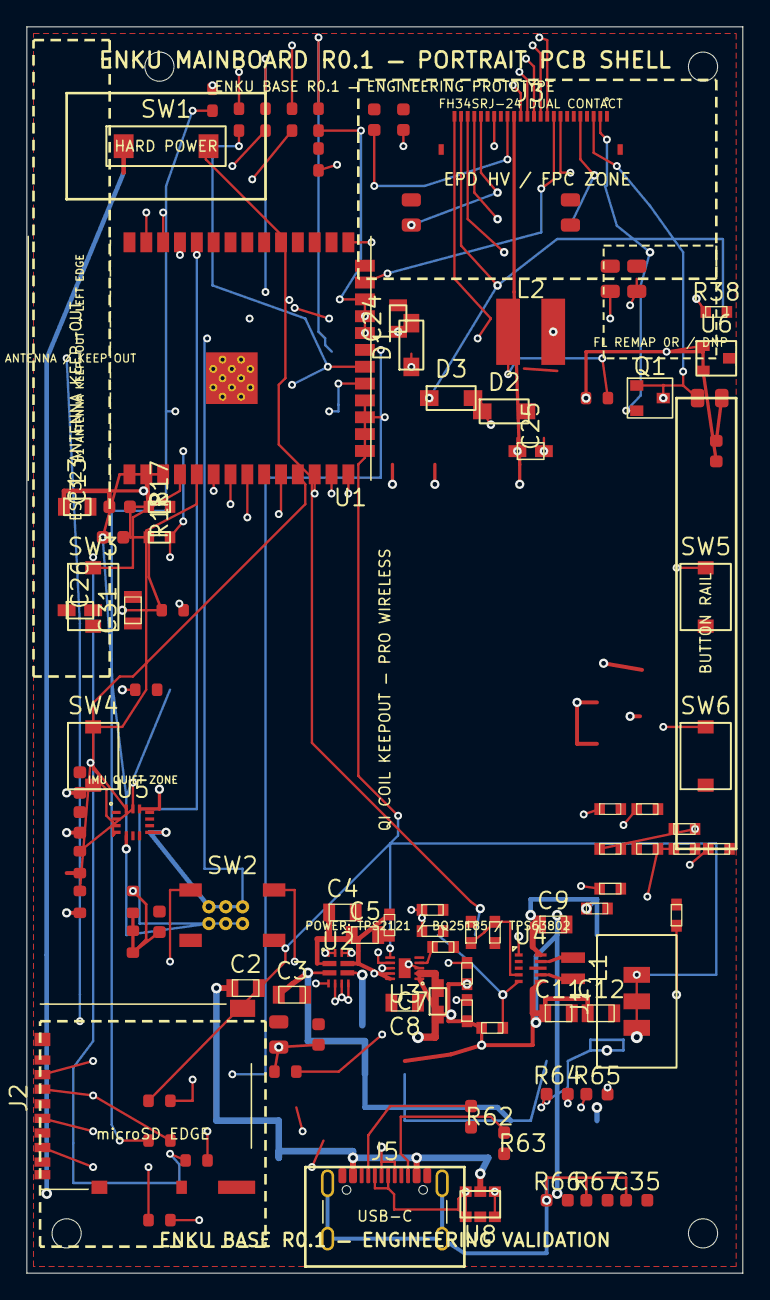
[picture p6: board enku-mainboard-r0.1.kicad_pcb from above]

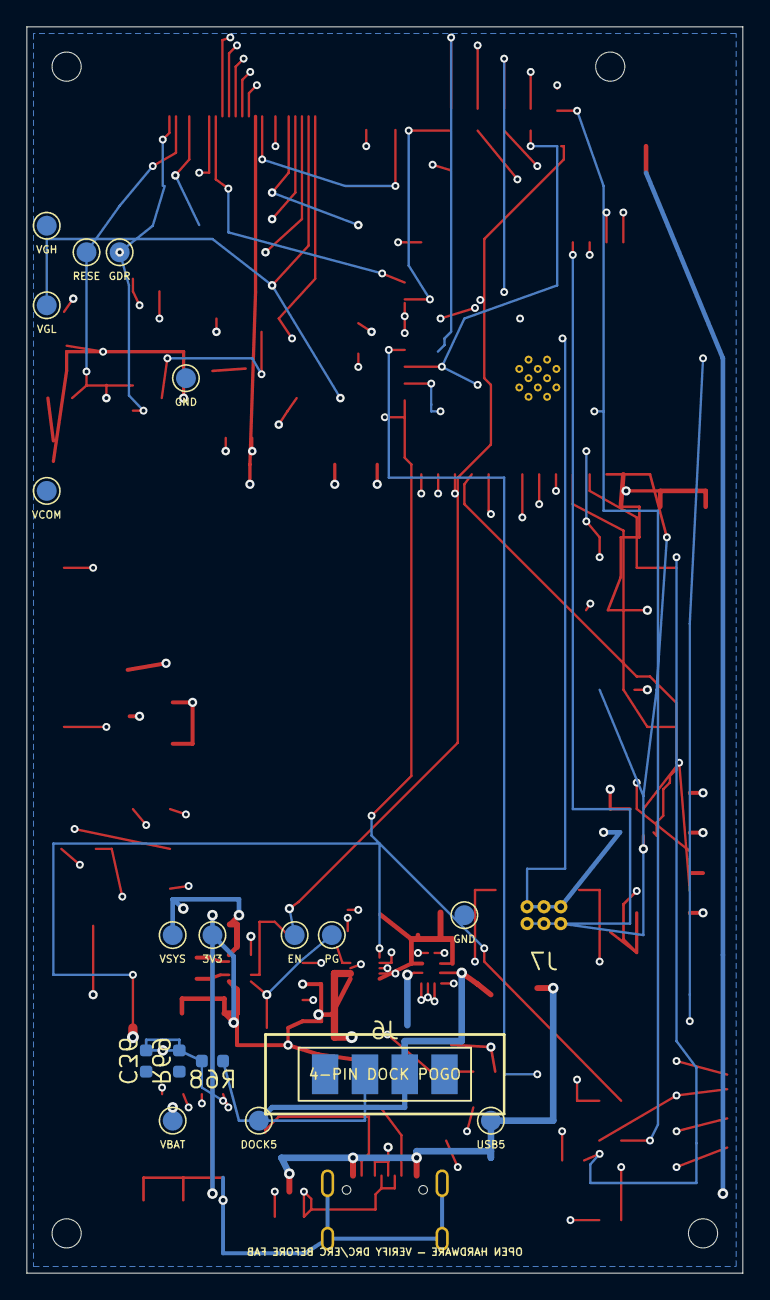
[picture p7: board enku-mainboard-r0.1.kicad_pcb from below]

Board: 4 copper layers, 54.0 x 94.0 mm, 122 parts (19 on the bottom side), 76 nets.

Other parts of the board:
H1, H2, H3, H4: MountingHole_2.2mm_M2

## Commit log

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2026-10-07 pcb: correct EPD 3V3 fanout and layer transition
    [enku-mainboard-r0.1.kicad_pcb]
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2026-10-07 pcb: correct Hall supply and charger battery escape
    [enku-mainboard-r0.1.kicad_pcb]
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2026-10-07 pcb: correct EPD and charger signal escapes
    [enku-mainboard-r0.1.kicad_pcb]
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2026-10-07 pcb: correct charger VBAT escape and SD card CS clearance
    [enku-mainboard-r0.1.kicad_pcb]
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2026-10-07 pcb: fix R28 layer transition closure
    [enku-mainboard-r0.1.kicad_pcb]
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2026-10-07 pcb: close final EPD reset routing island
    [enku-mainboard-r0.1.kicad_pcb]
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2026-10-07 pcb: revert dock regression and isolate MUX_PR1 from VSYS
    [enku-mainboard-r0.1.kicad_pcb]
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2026-10-07 pcb: move EPD reset closure off crowded In1 bus
    [enku-mainboard-r0.1.kicad_pcb]
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2026-10-07 pcb: reroute EPD reset clear of BOOT and ESP_EN
    [enku-mainboard-r0.1.kicad_pcb]
2026-10-07 pcb: restore C14 ground after reset reroute
    [enku-mainboard-r0.1.kicad_pcb]
2026-10-07 pcb: restore best DRC baseline after reset experiment
    [enku-mainboard-r0.1.kicad_pcb]
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2026-10-07 pcb: pull SD_CS trunk inside edge clearance
    [enku-mainboard-r0.1.kicad_pcb]
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2026-10-07 pcb: revert MUX_PR1 corridor regression
    [enku-mainboard-r0.1.kicad_pcb]
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2026-10-07 pcb: move EPD reset trunk out of boot and UART corridor
    [enku-mainboard-r0.1.kicad_pcb]
2026-10-07 pcb: revert EPD reset trunk regression
    [enku-mainboard-r0.1.kicad_pcb]
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2026-10-07 pcb: revert local SCL escape experiment
    [enku-mainboard-r0.1.kicad_pcb]
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2026-10-07 pcb: move EPD reset trunk off bottom control corridor
    [enku-mainboard-r0.1.kicad_pcb]
2026-10-07 pcb: nudge EPD reset dogleg below In2 crossing
    [enku-mainboard-r0.1.kicad_pcb]
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2026-10-07 pcb: revert VBUS_DOCK In2 regression
    [enku-mainboard-r0.1.kicad_pcb]
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2026-10-07 pcb: shift EPD reset trunk clear of U1 ground and BTN via
    [enku-mainboard-r0.1.kicad_pcb]
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2026-10-07 pcb: restore MUX PR1 endpoint and move VGL trunk to inner layer
    [enku-mainboard-r0.1.kicad_pcb]
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2026-10-07 pcb: restore VGL baseline while preserving safer local fixes
    [enku-mainboard-r0.1.kicad_pcb]
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2026-10-07 pcb: revert USB VBUS escape regression
    [enku-mainboard-r0.1.kicad_pcb]
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2026-10-07 pcb: route USB DM above VSYS and clear of dock sense ground
    [enku-mainboard-r0.1.kicad_pcb]
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2026-10-07 pcb: revert VSYS detour after DRC regression
    [enku-mainboard-r0.1.kicad_pcb]
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2026-10-07 pcb: jog EPD reset route clear of ESP ground pad column
    [enku-mainboard-r0.1.kicad_pcb]
2026-10-07 pcb: revert EPD reset jog after DRC regression
    [enku-mainboard-r0.1.kicad_pcb]
2026-10-07 pcb: revert MUX PR1 layer move after DRC regression
    [enku-mainboard-r0.1.kicad_pcb]
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2026-10-08 pcb: local EPD reset dogleg around MCU ground pads
    [enku-mainboard-r0.1.kicad_pcb]
2026-10-08 pcb: revert EPD reset jog that shorts BTN_L2
    [enku-mainboard-r0.1.kicad_pcb]
2026-10-08 pcb: restore R5 ground via, eliminate floating strap and PR1 clearance cluster
    [enku-mainboard-r0.1.kicad_pcb]
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2026-10-08 pcb: revert VSYS offset that introduced two shorts
    [enku-mainboard-r0.1.kicad_pcb]
2026-10-08 pcb: test VSYS central spine on In2 to avoid EPD SW and HALL In1 crossings
    [enku-mainboard-r0.1.kicad_pcb]
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2026-10-08 mechanical: add parametric 4-fastener display-clearance envelope
    [enku_fastener_envelope.scad]
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2026-10-08 mechanical: add asymmetric 3D stack with lower screws, upper hooks and collision markers
    [enku_asymmetric_assembly.scad]
2026-10-08 mechanical: calculate enclosure fit and quantify battery ESP32 collision
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2026-10-08 mechanical: document R05 assembly stack and unsolved component interference
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2026-10-08 pcb: connect R6 GND around MUX pad and correct R15 helper regex
    [enku-mainboard-r0.1.kicad_pcb]
2026-10-08 pcb: remove R2-shorting GND via and trial local R6 return
    [enku-mainboard-r0.1.kicad_pcb]
2026-10-08 pcb: trial narrow R5 GND escape; flag resistor cluster for full re-placement
    [enku-mainboard-r0.1.kicad_pcb]
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2026-10-08 mechanical: catch reversed microSD access orientation before enclosure freeze
    [enku-mainboard-r0.1.kicad_pcb]
2026-10-08 mechanical: stage corrected J2/J5 placements and coordinated reroute order
2026-10-08 mechanical: replace oversized switch candidate with LCSC miniature R22 edge study
    [enku-mainboard-r0.1.kicad_pcb]
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2026-10-08 research: fix KiCad handedness rotation sign and align actual 4-pad footprints with traces
    [enku-mainboard-r0.1.kicad_pcb]
2026-10-08 research: move tiny edge switch references to assembly Fab layer to avoid adjacent silkscreen
    [enku-mainboard-r0.1.kicad_pcb]
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2026-10-08 research: restore true outward C915811 handedness and enforce native pad vector gate
    [enku-mainboard-r0.1.kicad_pcb]
2026-10-08 research: sync per-component placement manifest and record native switch rotation correction
    [COMPONENT_AUDIT_R24.csv]
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2026-10-08 mechanical: reposition four rear M2 mounts; retain USB NPTH/PTH; gate holes and display stack
    [enku-mainboard-r0.2-placement.kicad_pcb]
2026-10-08 test: correct R25 drill parser syntax and rerun mounting gate
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2026-10-08 mechanical: block J3 FPC assembly until exact GDEY0397T81P tail drawing and pin1 verification
    [enku-mainboard-r0.2-placement.kicad_pcb]
2026-10-08 mechanical: mark exact Good Display stepped FPC tail and J3/H2 placement collision
    [enku-mainboard-r0.2-placement.kicad_pcb]
2026-10-08 test: audit all 24 real GDEY J3 pad nets and require stepped-flex fit and power checks
2026-10-08 R26 research: relocate J3, H2 and C28 together under Good Display side-offset flex
    [enku-mainboard-r0.3-fpc-trial.kicad_pcb]
2026-10-08 R27: replace rectangular FPC envelope with dimension-anchored stepped manufacturer profile
    [enku-mainboard-r0.4-stepped-fpc-trial.kicad_pcb]
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2026-10-08 R28: separate Base and Pro hardware; remove Hall U6 and C20 and Qi markings from Base PCB
    [enku-mainboard-r0.5-base-only.kicad_pcb, mcu_io.kicad_sch]
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2026-10-08 R29 Base: fix J2 SD resistor courtyard collisions and gate entire placement
    [enku-mainboard-r0.6-base-placement.kicad_pcb]
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2026-10-08 Correct Hirose J2 copper edge clearance by inward placement
    [enku-mainboard-r0.6-base-placement.kicad_pcb]
2026-10-08 Update R29 placement regression to cover the corrected J2 and microSD resistors
2026-10-08 CI: bootstrap KiCad libraries, classify native footprint mismatches, gate critical copper clearance
2026-10-08 manufacturing: record evidence-weighted PCBWay readiness at 30pct and native issue ledger
2026-10-08 layout: move legacy study annotations off Base fabrication silkscreen and remove frontlight ghost zone
    [enku-mainboard-r0.6-base-placement.kicad_pcb]
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2026-10-08 fix: normalize KiCad SWIG UTF8 library identifiers before pad geometry audit
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2026-10-08 audit: identify J7 Tag-Connect six plated-hole violation, missing NPTH guides and SW2 interference
2026-10-08 R30: rework J7 programming guide/contact geometry and J6 dock stencils; relocate BOOT, add DFM gates
    [enku-mainboard-r0.7-base-dfm-prep.kicad_pcb]
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2026-10-08 R30: align J6 bare contact BOM and J7 service header value with schematic
    [connectors.kicad_sch, enku-mainboard-r0.7-base-dfm-prep.kicad_pcb]
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2026-10-08 R31: remove three cross-component solder pad overlaps, mark diode cathodes, guard GCT pin map and audit hard-off
    [enku-mainboard-r0.8-base-assembly-placement.kicad_pcb]
2026-10-08 ci: fix R31 diode net assertion before first static validation
2026-10-08 R32: add real JST PH SMT battery header including two mechanical anchors
    [enku-mainboard-r0.9-base-jst-placement.kicad_pcb, power.kicad_sch]
2026-10-08 R32: validate JST PH anchor pads and battery pin order on active manufacturing placement
    [enku-mainboard-r0.9-base-jst-placement.kicad_pcb]
2026-10-08 R32: fix rotated JST pad copper short + schematic parity; guard intra-footprint net clearance
    [enku-mainboard-r0.9-base-jst-placement.kicad_pcb]
2026-10-08 ci: hard fail on R32 PCB/schematic parity and mask bridges, not just copper shorts
2026-10-08 R33: switch 3V3 converter VIN + EN + input capacitors downstream of mechanical SW1
    [enku-mainboard-r1.0-base-switched-vin.kicad_pcb, power.kicad_sch]
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2026-10-08 R34: add TMUX1101, divider isolation BAT_ADC_SW, C37 and R39 to physical PCB
    [enku-mainboard-r1.1-base-gated-battery-adc.kicad_pcb]
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2026-10-08 R34: place U9 TMUX1101, C37 decoupler and R39 SEL pulldown with schematic nets
    [mcu_io.kicad_sch]
2026-10-08 R34: add low-leakage battery sense gate, 123-pad assembly and Native KiCad release checks
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2026-10-08 ci: correct R34 board population size to 123 footprints including M2 holes
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2026-10-08 fix: snap TMUX1101 schematic to 1.27mm ERC grid and relocate five terminal labels
    [mcu_io.kicad_sch]
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2026-10-08 R34: physically justified ERC power source flags on switched SYS_EN and pack GND
    [mcu_io.kicad_sch, power.kicad_sch]
2026-10-08 R34: make native ERC zero-error a hard CI gate and record qualified schematic measurements
2026-10-08 R35: implement AO3401A high-side local PMOS switch and 100k gate pullup near regulator
    [enku-mainboard-r1.2-base-local-load-switch.kicad_pcb]
2026-10-08 R35: correct AO3401A gate/source real pinout and pin1 polarity mark
    [enku-mainboard-r1.2-base-local-load-switch.kicad_pcb]
2026-10-08 R35: define embedded PMOS load switch and change front slider to gate-to-ground only
    [power.kicad_sch]
2026-10-08 R35: wire AO3401A source VSYS/drain SYS_EN/gate PWR_GATE plus local pull-up R40 in KiCad schematic
    [power.kicad_sch]
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2026-10-08 ci: expose full native KiCad ERC details before preserving strict zero-error gate
2026-10-08 R35: repair premature PMOS symbol S-expression closure and restore full embedded 3-pin definition
    [power.kicad_sch]
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2026-10-08 R36: first 18 copper tracks and one through-via for local PMOS gate, VSYS and switched SYS_EN pilot
    [enku-mainboard-r1.3-base-first-power-copper.kicad_pcb]
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2026-10-08 R36: split SYS_EN trunk at 58.7/85.1 to eliminate first KiCad track_dangling error
    [enku-mainboard-r1.3-base-first-power-copper.kicad_pcb]
2026-10-08 R37: route charger VSYS to Q2 input plus 3V3 bulk outputs and rear testpoint, 19 tracks/5 vias
    [enku-mainboard-r1.4-base-charger-output-trial.kicad_pcb]
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2026-10-08 R38: build local In2.Cu GND return island with seven thermal/ground vias and ten F.Cu links
    [enku-mainboard-r1.5-base-ground-return-island.kicad_pcb]
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2026-10-08 R38: require native pcbnew GND zone refill and hard-fail dangling power-return vias
2026-10-08 ci: fix R38 zone-filled PCB artifact YAML list indentation
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2026-10-08 R39: add true microSD VDD pad4-to-C16 3V3 rail and GND return via; preserve USB native D+/D- wiring
    [enku-mainboard-r1.6-base-usb-msc-sd-power.kicad_pcb]
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2026-10-08 R40: reroute SD card VDD on In1 and fan out SCLK/MOSI on split copper layers with six through-vias
    [enku-mainboard-r1.7-base-sd-power-sclk-mosi.kicad_pcb]
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2026-10-08 R41: complete card-side SPI escapes and local SD decoupling; check active-board connectivity
    [enku-mainboard-r1.8-base-sd-card-completion.kicad_pcb]
2026-10-08 R41: connect all four MCU SPI nets to microSD resistor network with outboard MCU vias
    [enku-mainboard-r1.8-base-sd-card-completion.kicad_pcb]
2026-10-08 R41: implement switched-rail fail-safe VBUS comparator, discharge model, SD supply and dual ground references
    [enku-mainboard-r1.8-base-sd-card-completion.kicad_pcb, mcu_io.kicad_sch, power.kicad_sch]
2026-10-08 R41: correct ST ESD lands and route USB CC/VBUS power; fix GND clearances
    [connectors.kicad_sch, enku-mainboard-r1.8-base-sd-card-completion.kicad_pcb, power.kicad_sch]
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2026-10-08 R41: clear CC2 dock test pad; consolidate VBUS vias and archive Native diagnostics
    [enku-mainboard-r1.8-base-sd-card-completion.kicad_pcb]
2026-10-08 R41: move new plated via holes out of SD, comparator and USB SMD lands
    [enku-mainboard-r1.8-base-sd-card-completion.kicad_pcb]
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2026-10-08 R41: clear card shell return from MISO and register every active-board part
    [COMPONENT_AUDIT_R41.csv, enku-mainboard-r1.8-base-sd-card-completion.kicad_pcb]
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2026-10-08 R42 route MCU supply, reset/BOOT service and regulator feedback; verify native copper
    [COMPONENT_AUDIT_R42.csv, enku-mainboard-r1.9-base-mcu-power-control.kicad_pcb]
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2026-10-08 R43: join local C26 EPD bypass and C18/C19 IMU bulk GND to reading button plane returns
    [enku-mainboard-r2.0-base-reading-ground-returns.kicad_pcb]
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2026-10-08 R43 DFM: move SW3 GND stitching via away from C31 EPD_VCI SMT land
    [enku-mainboard-r2.0-base-reading-ground-returns.kicad_pcb]
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2026-10-08 R43: archive verified side-button GND Native KiCad results, DFM via fix and 146 unrouted remaining
2026-10-09 R44: physically connect hard-power SW1 gate to Q2 PMOS and switch ground, preserving charger always-on path
    [enku-mainboard-r2.1-base-sw1-gate-trial.kicad_pcb]
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2026-10-09 R44 DFM: reroute remote PMOS gate around J7 TagConnect NPTH guide holes; retain strict hole clearance checks
    [enku-mainboard-r2.1-base-sw1-gate-trial.kicad_pcb]
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2026-10-09 R47: archive Native-verified four-button GPIO and post-BOOT-clearance PCBWay readiness (139 unrouted)
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2026-10-09 R48: replace frozen 30 percent with transparent 43 point engineering score and independent PCBWay no-go gate
2026-10-09 R48: record verified 56 silk-DRC fixes and 44 percent evidence-weighted PCBWay engineering readiness
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2026-10-10 hardware: preserve recovered R119 layout and verified R118 source [skip ci]
    Persist the KiCad 10.0.7 project before the next routing pass. The recovered layout has 67 opens, ERC 0, parity 0 and zero RF keepout violations; routing is incomplete and fabrication is blocked. Preserve all pad and surviving copper net identities and retain an immutable R118 source archive.
    [connectors.kicad_sch, enku-mainboard-r0.1.kicad_pcb, epd_hv.kicad_sch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]
2026-10-10 ci: compare R119 with exact KiCad 10.0.7 and retire obsolete gates
    Check source hash, actual pad/copper identity, all DRC errors and ERC against the committed local checkpoint. Report fabrication NO FAB separately from a matching diagnostic result. Run once on this workflow change; do not spend Actions minutes on every subsequent copper edit.
2026-10-10 R120: restore 59 native-verified routes and checkpoint 8 remaining opens [skip ci]
    Preserve all 400 original pads and surviving copper net identities. Full KiCad 10.0.7 DRC/zone refill/parity and ERC evidence retained. Manufacturing remains NO FAB.
    [enku-mainboard-r0.1.kicad_pcb]
2026-10-10 R120: correct Hirose J3 lands/stencil and close Tag-Connect reset
    Native KiCad 10.0.7 verifies six remaining opens, all USB. Preserve all original pad/copper net identities and connected pad groups. Remove only isolated VGH copper and the obsolete BOOT leaf stub. Run one exact-version server comparison; fabrication remains NO FAB.
    [enku-mainboard-r0.1.kicad_pcb]
2026-10-10 R120: move C28 ground drill outside its SMD land and retain physical audit
    Preserve via/copper UUIDs and net identities; move only the GND fanout 0.45 mm. All 67 new via annuli and all Tag-Connect foreign B-side copper pass the independent geometry audit. Native DRC remains six USB opens, ERC/parity zero. Verify the corrected source on the exact KiCad server gate.
    [enku-mainboard-r0.1.kicad_pcb]
2026-10-10 docs: retain successful exact KiCad R120 server comparison [skip ci]
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2026-10-10 Record R121 server proof and manufacturer footprint triage [skip ci]
    Retain actual server comparison and USB refilled-plane audit. Flag the confirmed Q1 gate/source location mirror for R122. No PCB or rules changes.
2026-10-10 R122: correct Q1 manufacturer Gate/Source pad locations
    Fix mirrored IRLML6346 gate/source geometry using Infineon top view. Preserve pad UUIDs, numbers and nets; reroute gate/source and clear the original testpoint via. Exact two pad-position changes, all other pad geometry and footprint placements preserved. Full KiCad 10.0.7: zero opens/ERC/parity, 115 inherited DRC; USB reference and via/Tag-Connect audits pass. Add an independent server Q1 pin-order guard. NO FAB.
    [enku-mainboard-r0.1.kicad_pcb]
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2026-10-10 R124: restore approved SW1, correct common pin and route upper-edge switch
    Replace the two-pad placeholder with the approved MK-12C03-G015 three-terminal symbol and reviewed physical footprint. Preserve R29 ground and the U1 RF keepout. Native local: zero opens/ERC/parity, 109 library mismatches and 20 active hole findings. Add physical/netlist SW1 regression guard and retain A0/X1 land-pattern and mechanical-datum HOLD; NO FAB.
    [enku-mainboard-r0.1.kicad_pcb, power.kicad_sch]
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2026-10-10 R125: correct manufacturer Q1/Q2/U9 lands and guard full copper, netlist and assembly layers
    [enku-mainboard-r0.1.kicad_pcb, epd_hv.kicad_sch, mcu_io.kicad_sch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]
2026-10-11 R126: select 61 exact components, correct physical lands and local routing, preserve full source; NO FAB
    [connectors.kicad_sch, enku-mainboard-r0.1.kicad_pcb, epd_hv.kicad_sch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]
2026-10-11 R127: finish passive MPN selection and correct USB VBUS capacitance
    Select exact parts and nominal lands for the remaining 15 capacitors and R70/R71/R37. Reduce C4 from10uF/10V to1uF/25V, taking direct VBUS capacitance from15.8 to6.8uF. Preserve all417 original pad and2639 Cu identities/nets, with only3 declared EPD_VCI vertex adjustments.
    Native KiCad10.0.7: opens0/ERC0/parity0/DRC47(27library+20holes). Add independent79-part, source and native-netlist numeric power guards. Record unqualified Ceff, inrush, EPD pulse/process gates; NO FAB.
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2026-10-11 R129: fix IC stencil apertures, pin-1 marking and native assembly classification
    Verify six active IC pin maps and 97 native CPL placements. Preserve all 425 original pads, nets and 2639 tracks/vias; retain the 20 active intrinsic hole-clearance findings as fabrication gates. Add independent native KiCad checks and exact source-preservation guards.
2026-10-11 R129: retain actual successful native KiCad CI evidence and bounded hours
    Capture run 38136336929 / job 114460858170, all 12 successful steps and 16 actual job-log reports. Confirm 0 opens/ERC/parity/library warnings, 20 retained hole-clearance findings and 97 native CPL placements. Evidence-only follow-up preserves every tested hardware, workflow and script blob; fabrication remains gated.
2026-10-11 R130 BAT-REV3: PH2 battery and separate NTC; correct Laird lands and preserve R129
    Implement the two-wire battery interface, retain all accepted copper identities, and restore the L2 land/via correction. Add native source/assembly/plot guards, supplier evidence and dimensional studies. Charging temperature, capacity/timer, complete mechanical fit and twenty hole findings remain HOLD; no fabrication or orders.
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2026-10-11 R131: select thinner 335084 cell and check fixed-thickness packaging
    Retain exact R130 hardware and native evidence. Compare primary catalogue rows, recheck existing RFQs, and preserve an analytical/CAD audit of PH-2 conflicts. No case thickness increase, purchases or mechanical release.
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2026-10-12 R134 working checkpoint: real USB4215 replacement and GPIO charger control; ten routes pending, NO FAB
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2026-10-12 R135 native DRC/ERC/parity zero after genuine no-boss switches and TS bias correction; independent audits pending, NO FAB
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2026-10-12 R136: increase TPS63802 input C9 to22uF, preserve R135 geometry and enable immutable main/PR checks; NO FAB
    Replace only four C9 properties in PCB/power source; all127 placements,438 pads,3707 copper items and nets remain unchanged. Review exact DC-bias scenarios and the0.95-to1.45mm local height change. Retain1140 R135 files, licensing and all history. Native local DRC/ERC/opens/parity0,23 scopes and8 rejection cases pass; actual immutable CI pending. Read existing supplier replies without outreach, manufacturing or purchasing.
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2026-10-13 Package exact R138 Gerber/BOM/CPL uploads and full140-file review; correct USB J5 documentation; NO FAB
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2026-10-14 R142: correct reset/panel supply and SD pullups; add independent Gerber verification (NO FAB)
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2026-10-14 R143: publish verified PCBWay review packet, drawings, pilot procedures and startup design blockers [skip ci]
2026-10-14 docs(r144): preserve power redesign checkpoint and unresolved acceptance checks
2026-10-14 hardware(r144): restore reproducible power/reset proposal, routing and acceptance pending
2026-10-14 hardware(r144): route precision reset and PWM supply, fix rule compilation; native checks zero, independent review pending
2026-10-15 R144: synchronize schematic titles and confirmed panel annotation; correct informational divider current
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2026-10-15 docs(r147): record display-FPC entry conflicts and critical capacitor clearance add-on
2026-10-15 R148: free J3 approach and replace tall battery header with wire lands
    Relocate the obstructing e-paper components and reroute the local power/control nets. Preserve J3 pin mapping, all USB geometry, mounting datums, electrical topology and the six explicit filled/capped via requests. J1 retains its original VBAT/GND copper lands as a no-paste bare-PCB interface with case-clamp documentation.
    Add strict R148 intended-delta and bounded mechanical guards; retain historical checks and negative fixtures. Local complete native and independent Gerber verification passes. Actual folded-FPC fit, harness/clamp and bench/factory qualification remain HOLD / NO FAB.
2026-10-15 docs(r148): publish verified mechanical review, manufacturing exports and downloads
    Record actual source-pinned CI proof and R148 enclosure CAD datums; update the branch README, bilingual review, handoff, artifact checksums and bounded hours. Retain full folded-flex, harness and physical qualification holds.
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2026-10-25 r149-p1: document 2D clearance evidence, 44 affected nets and USB/H4 screw-head hold
2026-10-25 ci(r149-p1): exact KiCad native DRC diagnostic for sha-pinned M03 clearance, unroute HOLD
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2026-10-25 fix(r149-p2): preserve KiCad root header in generated native PCB
2026-10-25 docs(r149-p2): record native 78→53 DRC, 4→0 shorts, 62 opens and remaining mechanical hard blocks
2026-10-25 r149-p3: fix antenna keepout and H4 clearance geometries; connect switch pad pairs, retain NO FAB
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2026-10-25 r149-p4: reroute BTN_L2 around existing ground via and fix USB silk/H4 clearance
2026-10-25 ci(r149-p4): evaluate exact bypass and silkscreen clearance, zero-shorts invariant
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2026-10-25 fix(r149-p5): maintain >=0.2mm VBAT-to-ground trace clearance at battery J1
2026-10-25 ci(r149-p5): pin corrected ground route SHA and rerun native clearance
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
